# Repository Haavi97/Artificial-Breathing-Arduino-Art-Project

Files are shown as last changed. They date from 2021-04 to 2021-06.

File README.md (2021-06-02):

# Artificial-Breathing-Arduino-Art-Project
>Art project representing and organism breathing using Arduino. All the artistic part has been done by Juss Heinsalu

## Hardware
Finally the microcontrollers have been
- 2 Arduino Nano (had to solve driver problems with original board: [link](https://www.usb-drivers.org/ft232r-usb-uart-driver.html))
- ESP-01 (ESP8266)

## Scripts used
1. [arduino.ino](breathing-esp+arduino/arduino/arduino.ino)
2. [arduino2.ino](breathing-esp+arduino/arduino2/arduino2.ino)
3. [esp.ino](breathing-esp+arduino/esp/esp.ino)

First script is used for controlling the pump, vacuum pump and the big compressor (12V).
  
The second one is used to controlled the servo motor that serves as a valve for the "organism" 
connected to the compressor in order to regulate the out going air flow. The servo is controlled with a separate Arduino because of hardware constraints, power suppli couln't handle relays and servo at the same time.

The third is for serving as an interface for wirelessly set the parameters of the system: in time, pause, out time for each of the pump/compressor.

## Circuit Sketch
Everything is connected to a big power supply with enough amperage for all the motors.
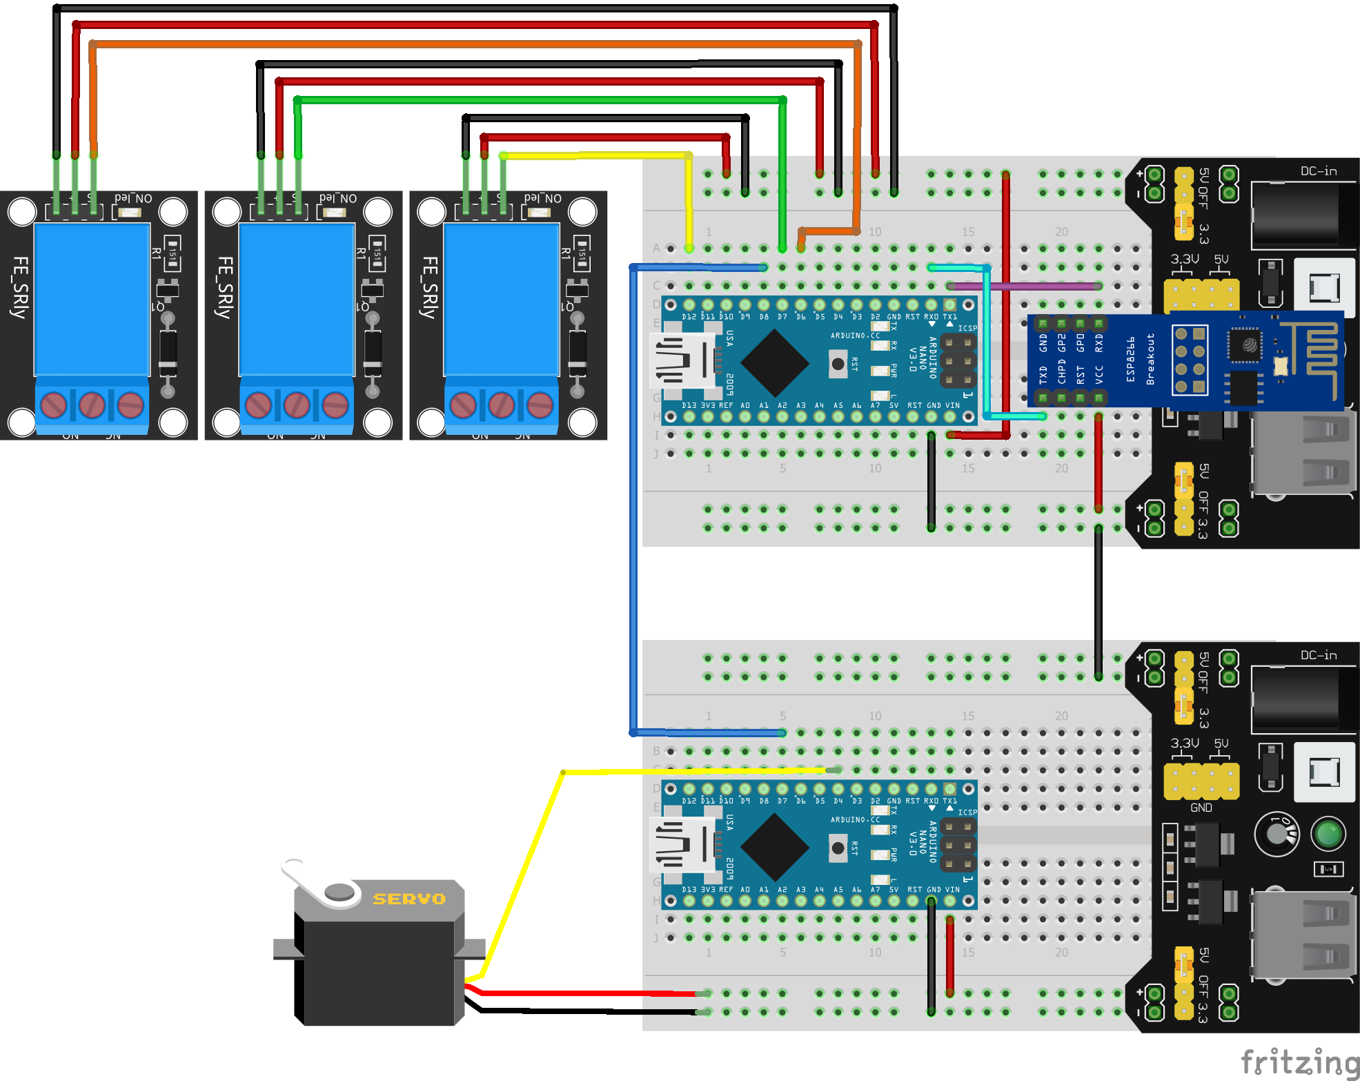
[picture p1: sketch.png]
Circuit sketch


## Unmounted system
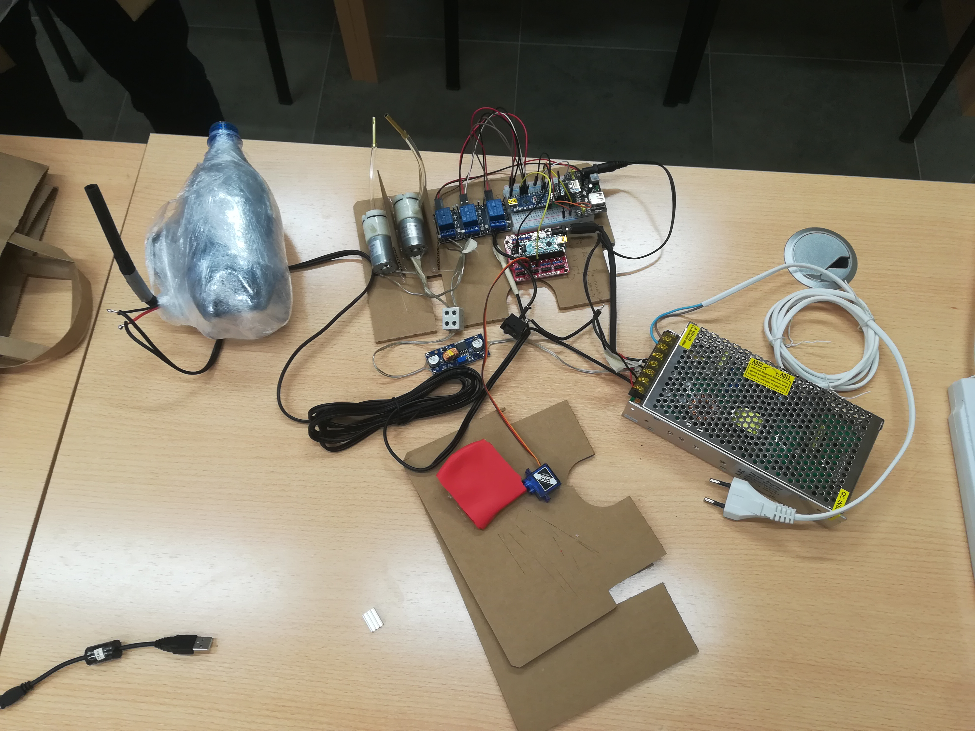
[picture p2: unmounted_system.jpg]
Unmounted system


## Part of the exhibition Taganemisteeta
[FB event](https://www.facebook.com/events/4201697879861242/?acontext=%7B"ref"%3A"52"%2C"action_history"%3A"[%7B%5C"surface%5C"%3A%5C"share_link%5C"%2C%5C"mechanism%5C"%3A%5C"share_link%5C"%2C%5C"extra_data%5C"%3A%7B%5C"invite_link_id%5C"%3A1373041676388522%7D%7D]"%7D)
[NART exhibition](https://www.nart.ee/en/exhibitions/nart-annual-exhibition-2021-point-of-no-return-attunement-of-attention/)

## Video of one of the organisms
[video](https://user-images.githubusercontent.com/57443449/120454942-010f6500-c39d-11eb-900f-e86b6011543a.mp4)

## Contact
Email: <fortin@taltech.ee>

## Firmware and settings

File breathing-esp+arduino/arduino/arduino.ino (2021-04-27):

/**
 * File:        breathing-esp.ino
 * Author:      Francisco Javier Ortín Cervera
 * Created:     17.04.2021
 * Last edit:   18.04.2021
 *
 * Description: Program for representing the breathing of
 *              a living organism using a compressor
 *              controlled by a relay from one hand and  
 *              another compressor and a vacuum pump also 
 *              controlled with relays.
 *              Part of the program that goes to the Arduino 
 *              that receives commands from an ESP-01 in 
 *              this case.
 * 
  */
  
#include <EEPROM.h>

unsigned long EEPROM_readlong(int address);
void EEPROM_writelong(int address, unsigned long value);
void EEPROM_writeint(int address, int value);
unsigned int EEPROM_readint(int address);

// Setting pin numbers
int const vacuum = 6;
int const pump = 7;
int const compressor = 12;
int const servoPin = 8;

unsigned long current = millis();

unsigned long last_vacuum = millis();
unsigned long last_pump = millis();
unsigned long last_compressor = millis();

unsigned long vacuum_time = EEPROM_readlong(0);
unsigned long pvp_time = EEPROM_readlong(5);
unsigned long pump_time = EEPROM_readlong(10);
unsigned long pause_time = EEPROM_readlong(15);
unsigned long compressor_time = EEPROM_readlong(20);
unsigned long compressor_pause = EEPROM_readlong(25);

int closed_angle = 90;
// initial angle at which the valve is closed

int open_angle = 10;
// angle at which the valve is open

bool print_compressor_pause = true;
bool print_pump = true;
bool print_vacuum = true;
bool to_update = true;

bool activeCompressor = true;
bool activePump = true;

String input = "";

void setup(){  
  pinMode(compressor, OUTPUT);
  pinMode(pump, OUTPUT);
  pinMode(vacuum, OUTPUT);

  pinMode(servoPin, OUTPUT);
  
  // Serial port for debugging purposes
  Serial.begin(115200);

  digitalWrite(compressor, HIGH);
  digitalWrite(servoPin, HIGH);
  digitalWrite(vacuum, HIGH);
  digitalWrite(pump, LOW);
}
  
void loop() {
  current = millis();
  if (activeCompressor) {
    if (current > (last_compressor + compressor_time + compressor_pause)){
      if (to_update){
        Serial.println("Compressor ON");
        digitalWrite(servoPin, HIGH);
        digitalWrite(compressor, HIGH);
        last_compressor = current;
        print_compressor_pause = true;
        to_update = false;
      }
    } else if (current > (last_compressor + compressor_time)){
      if (print_compressor_pause){
        Serial.println("Compressor OFF");
        digitalWrite(servoPin, LOW);
        digitalWrite(compressor, LOW);
        print_compressor_pause = false;
        to_update = true;
      }
    }
  } else{
      digitalWrite(servoPin, LOW);
      digitalWrite(compressor, LOW);
  }
    
  if (activePump){
    if (current > (last_vacuum + vacuum_time + pause_time + pump_time + pvp_time)){
      Serial.println("Pump OFF");
      digitalWrite(pump, LOW);
      Serial.println("Vacuum ON");
      digitalWrite(vacuum, HIGH);
      last_vacuum = current;
      print_vacuum = true;
      print_pump = true;
    } else if (current > (last_vacuum + vacuum_time + pause_time + pump_time)){
      digitalWrite(pump, LOW);
    } else if (current > (last_vacuum + vacuum_time + pause_time)){
      if (print_pump){
        Serial.println("Pump ON");
        digitalWrite(pump, HIGH);
        print_pump = false;
      }
    } else if (current > (last_vacuum + vacuum_time)){
      if (print_vacuum){
        Serial.println("Vacuum OFF");
        digitalWrite(vacuum, LOW);
        print_vacuum = false;
      }
    }
  } else {
    digitalWrite(vacuum, LOW);
    digitalWrite(pump, LOW);
  }
  
  if (Serial.available()){
    input = Serial.readStringUntil('\n');
    if (input[0] == 'p'){
      input.remove(0, 1);
      pump_time = input.toInt();
      Serial.println(pump_time);
      last_compressor = current;
      last_vacuum = current;
    } else if (input[0] == 'v'){
      input.remove(0, 1);
      vacuum_time = input.toInt();
      Serial.println(vacuum_time);
      last_compressor = current;
      last_vacuum = current;
    } else if (input[0] == 'a'){
      input.remove(0, 1);
      pause_time = input.toInt();
      Serial.println(pause_time);
      last_compressor = current;
      last_vacuum = current;
    } else if (input[0] == 'c'){
      input.remove(0, 1);
      compressor_time = input.toInt();
      Serial.println(compressor_time);
      last_compressor = current;
      last_vacuum = current;
    } else if (input[0] == 'r'){
      input.remove(0, 1);
      compressor_pause = input.toInt();
      Serial.println(compressor_pause);
      last_compressor = current;
      last_vacuum = current;
    } else if (input[0] == 's'){
      input.remove(0, 1);
      pvp_time = input.toInt();
      Serial.println(compressor_pause);
      last_compressor = current;
      last_vacuum = current;
    } else if (input[0] == 'k'){
      activeCompressor = !activeCompressor;
      EEPROM_writelong(0, vacuum_time);
      EEPROM_writelong(5, pvp_time);
      EEPROM_writelong(10, pump_time);
      EEPROM_writelong(15, pause_time);
      EEPROM_writelong(20, compressor_time);
      EEPROM_writelong(25, compressor_pause);
      Serial.println(vacuum_time);
      Serial.println(pvp_time);
      Serial.println(pump_time);
      Serial.println(pause_time);
      Serial.println(compressor_time);
      Serial.println(compressor_pause);
    } else if (input[0] == 'q'){
      activePump = !activePump;
    }
  }
}


// from: https://forum.arduino.cc/t/saving-an-unsigned-long-int-to-internal-eeprom/487205
// read double word from EEPROM, give starting address
 unsigned long EEPROM_readlong(int address)
 {
 //use word read function for reading upper part
 unsigned long dword = EEPROM_readint(address);
 //shift read word up
 dword = dword << 16;
 // read lower word from EEPROM and OR it into double word
 dword = dword | EEPROM_readint(address+2);
 return dword;
}

//write word to EEPROM
 void EEPROM_writeint(int address, int value) 
{
 EEPROM.write(address,highByte(value));
 EEPROM.write(address+1 ,lowByte(value));
}
 
 //write long integer into EEPROM
 void EEPROM_writelong(int address, unsigned long value) 
{
 //truncate upper part and write lower part into EEPROM
 EEPROM_writeint(address+2, word(value));
 //shift upper part down
 value = value >> 16;
 //truncate and write
 EEPROM_writeint(address, word(value));
}

unsigned int EEPROM_readint(int address) 
{
 unsigned int word = word(EEPROM.read(address), EEPROM.read(address+1));
 return word;
}

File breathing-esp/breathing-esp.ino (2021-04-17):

/**
 * File:        breathing-esp.ino
 * Author:      Francisco Javier Ortín Cervera
 * Created:     17.04.2021
 * Last edit:   17.04.2021
 *
 * Description: Program for representing the breathing of
 *              a living organism using a compressor
 *              controlled by a relay from one hand and  
 *              another compressor and a vacuum pump also 
 *              controlled with relays.
 * 
  */


#include <WiFi.h>
#include <AsyncTCP.h>
#include <ESPAsyncWebServer.h>

#include "breathing-esp.h"

// Setting pin numbers
int const vacuum = 2;
int const pump = 0;
int const compressor = 4;

unsigned long current = millis();

unsigned long last_vacuum = millis();
unsigned long last_pump = millis();
unsigned long last_compressor = millis();

unsigned long vacuum_time = 10000;
unsigned long pump_time = 10000;
unsigned long pause_time = 10000;
unsigned long compressor_time = 10000;
unsigned long compressor_pause = 10000;

bool print_compressor_pause = true;
bool print_pump = true;
bool print_vacuum = true;

// Credentials already defined in header file breathing-esp.h
// const char* ssid = "REPLACE_WITH_YOUR_SSID";
// const char* password = "REPLACE_WITH_YOUR_PASSWORD";

// Set your Static IP address
IPAddress local_IP(192, 168, 1, 8);
// Set your Gateway IP address
IPAddress gateway(192, 168, 1, 1);

IPAddress subnet(255, 255, 0, 0);

// 1: Vacuum pump
// 2: Pump
// 3: Pause
// 4: Compressor
// 5: Compressor pause

String slider1Value = "1000";
String slider2Value = "1000";
String slider3Value = "1000";
String slider4Value = "1000";
String slider5Value = "1000";

// setting PWM properties
const int freq = 5000;
const int ledChannel = 0;
const int resolution = 8;

const char* PARAM_INPUT = "value";
const char* PARAM_INPUT2 = "id";

// Create AsyncWebServer object on port 80
AsyncWebServer server(80);

const char index_html[] PROGMEM = R"rawliteral(
<!DOCTYPE HTML><html>
<head>
  <meta name="viewport" content="width=device-width, initial-scale=1">
  <title>ESP Web Server</title>
  <style>
    html {font-family: Arial; display: inline-block; text-align: center;}
    h2 {font-size: 2.3rem;}
    p {font-size: 1.9rem;}
    body {max-width: 400px; margin:0px auto; padding-bottom: 25px;}
    .slider { -webkit-appearance: none; margin: 14px; width: 360px; height: 25px; background: #FFD65C;
      outline: none; -webkit-transition: .2s; transition: opacity .2s;}
    .slider::-webkit-slider-thumb {-webkit-appearance: none; appearance: none; width: 35px; height: 35px; background: #003249; cursor: pointer;}
    .slider::-moz-range-thumb { width: 35px; height: 35px; background: #003249; cursor: pointer; } 
  </style>
</head>
<body>
  <h2>Breathing control panel</h2>
  <p>Vacuum in: <span id="vacuumSliderValue">%SLIDERVALUE1%</span></p>
  <p><input type="range" onchange="updateSliderPWM(this, 1)" id="vacuumSlider" min="0" max="10000" value="%SLIDERVALUE1%" step="1" class="slider"></p>
  
  <p>Pump: <span id="pumpSliderValue">%SLIDERVALUE2%</span></p>
  <p><input type="range" onchange="updateSliderPWM(this, 2)" id="pumpSlider" min="0" max="10000" value="%SLIDERVALUE2%" step="1" class="slider"></p>
  
  <p>Pause: <span id="Pause">%SLIDERVALUE3%</span></p>
  <p><input type="range" onchange="updateSliderPWM(this, 3)" id="PauseSlider" min="0" max="10000" value="%SLIDERVALUE3%" step="1" class="slider"></p>
  
  <p>Compressor: <span id="compressorSliderValue">%SLIDERVALUE4%</span></p>
  <p><input type="range" onchange="updateSliderPWM(this, 4)" id="compressorSlider" min="0" max="10000" value="%SLIDERVALUE4%" step="1" class="slider"></p>
  
  <p>Compressor pause: <span id="compressorPause">%SLIDERVALUE5%</span></p>
  <p><input type="range" onchange="updateSliderPWM(this, 5)" id="compressorPauseSlider" min="0" max="10000" value="%SLIDERVALUE5%" step="1" class="slider"></p>
<script>
function updateSliderPWM(element, idn) {
  switch(idn){
    case 1:
      var id = "vacuumSliderValue";
      var sliderValue = document.getElementById("vacuumSlider").value;
      break;
    case 2:
      var id = "pumpSliderValue";
      var sliderValue = document.getElementById("pumpSlider").value;
      break;
    case 3:
      var id = "Pause";
      var sliderValue = document.getElementById("PauseSlider").value;
      break;
    case 4:
      var id = "compressorSliderValue";
      var sliderValue = document.getElementById("compressorSlider").value;
      break;
    case 5:
      var id = "compressorPause";
      var sliderValue = document.getElementById("compressorPauseSlider").value;
      break;
  }
  document.getElementById(id).innerHTML = sliderValue;
  console.log(sliderValue);
  var xhr = new XMLHttpRequest();
  xhr.open("GET", "/slider?value="+sliderValue+"&id="+idn.toString(), true);
  xhr.send();
}
</script>
</body>
</html>
)rawliteral";

// Replaces placeholder with button section in your web page
String processor(const String& var){
  //Serial.println(var);
  if (var == "SLIDERVALUE1"){
    return slider1Value;
  } else if (var == "SLIDERVALUE2"){
    return slider2Value;
  } else if (var == "SLIDERVALUE3"){
    return slider3Value;
  } else if (var == "SLIDERVALUE4"){
    return slider4Value;
  } else if (var == "SLIDERVALUE5"){
    return slider5Value;
  }
  return String();
}
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

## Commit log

2021-01-29 Arduino code
2021-01-29 Update README.md
    Arduino Nano testing problems added to Readme file
2021-02-01 Forgot to add files in previous commit
    [sketch.fzz]
2021-02-04 Valve control planned
    [sketch.fzz]
2021-04-17 Control with an ESP32. Sketch should be updated
2021-04-17 Because of problems with powering the Lora Heltec Wifi Stick Lite I have swtched to program an ESP-01 that communicates to an Arduino Nano (others would work as well
    [arduino.ino, esp.ino]
2021-04-18 A lot of bugs and small things fixed. Also, added some functionality
    [arduino.ino, esp.ino]
2021-04-18 Added an axuliary Arudino board because of power problems. I think that the 5V power supply just cannot handle 3 relays and a servo at the same time. And since I don't have a servo driver at hand I j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
    [arduino.ino, arduino2.ino, esp.ino]
